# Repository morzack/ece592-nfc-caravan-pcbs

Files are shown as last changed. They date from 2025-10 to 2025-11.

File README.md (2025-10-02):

# ece592-nfc-caravan-pcbs

submodules vendor in reference boards for tt06 and caravel.

most up-to-date caravel evaluation PCB at `caravel_board/hardware/development/caravel-dev-v5-M.2` -- this contains details on FTDI module and flash memory for bringup of on-chip VexRiscv management CPU

## work breakdown

following a top-down design

1. make symbol for pinout (actual)
2. identify routing constaints for breakout
3. make block diagram of off-chip requirements for bringup
4. implement schematics for off-chip stuff
5. layout, etc

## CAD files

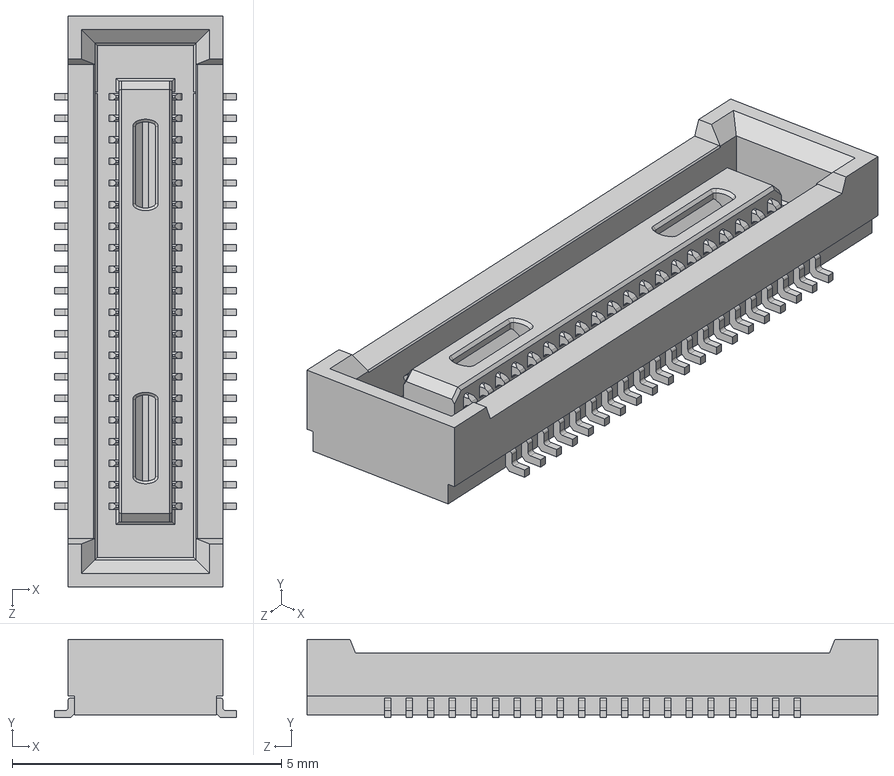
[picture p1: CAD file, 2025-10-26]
3D/DF40C-40DS-0.4V_51_.stp
3.38 x 1.45 x 10.6 mm

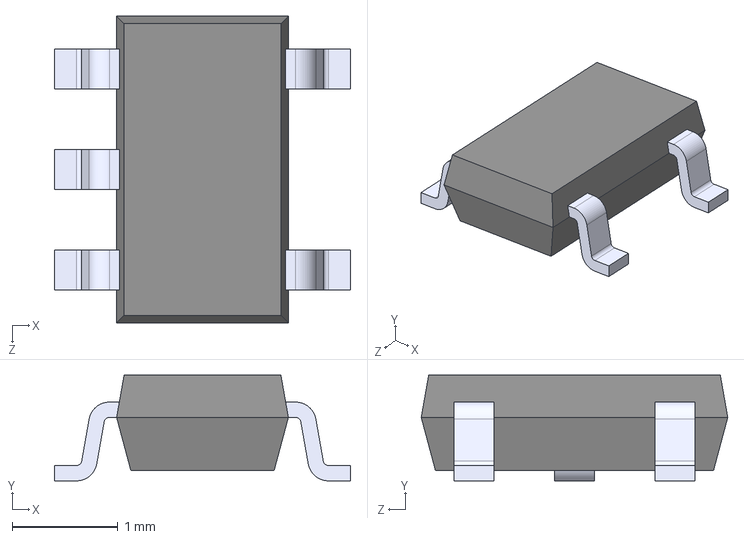
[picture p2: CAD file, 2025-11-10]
LT1761ES5_BYP_TRMPBF/LT1761ES5-BYPTRMPBF.step
2.80 x 1.00 x 2.90 mm

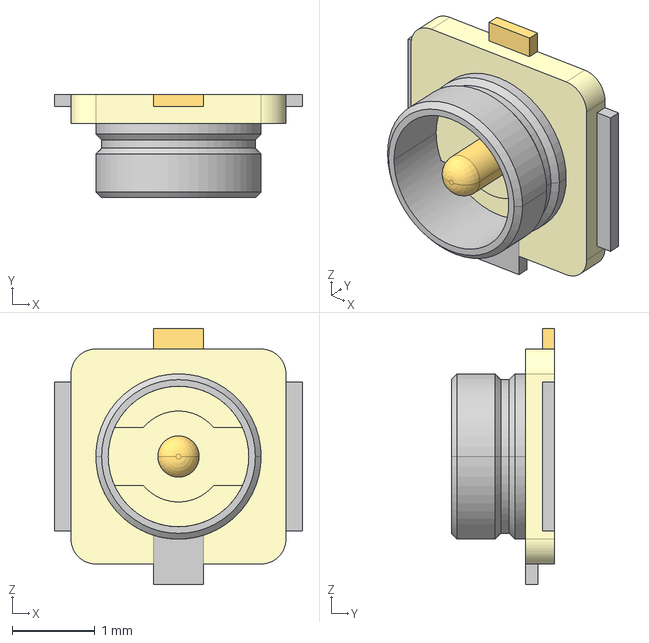
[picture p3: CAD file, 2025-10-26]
3D/U.FL-R-SMT-1_80_.stp
3.00 x 1.25 x 3.10 mm

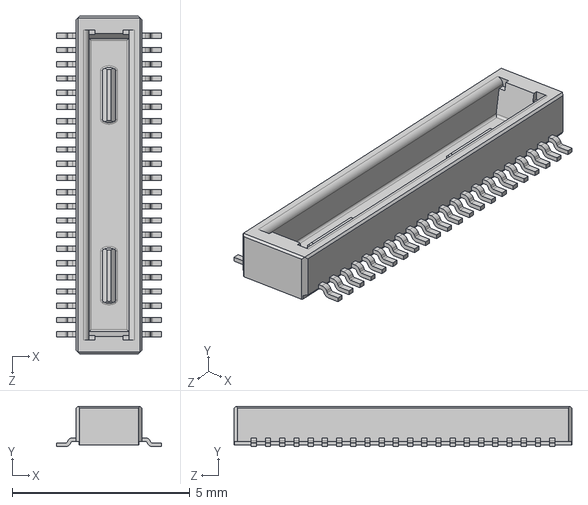
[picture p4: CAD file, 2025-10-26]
3D/DF40C-40DP-0.4V_51_.stp
2.97 x 1.14 x 9.52 mm

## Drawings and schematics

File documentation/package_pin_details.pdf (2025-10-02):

## Pad Assign Information

ESD | NO ESD | CLAMP | NO ESD

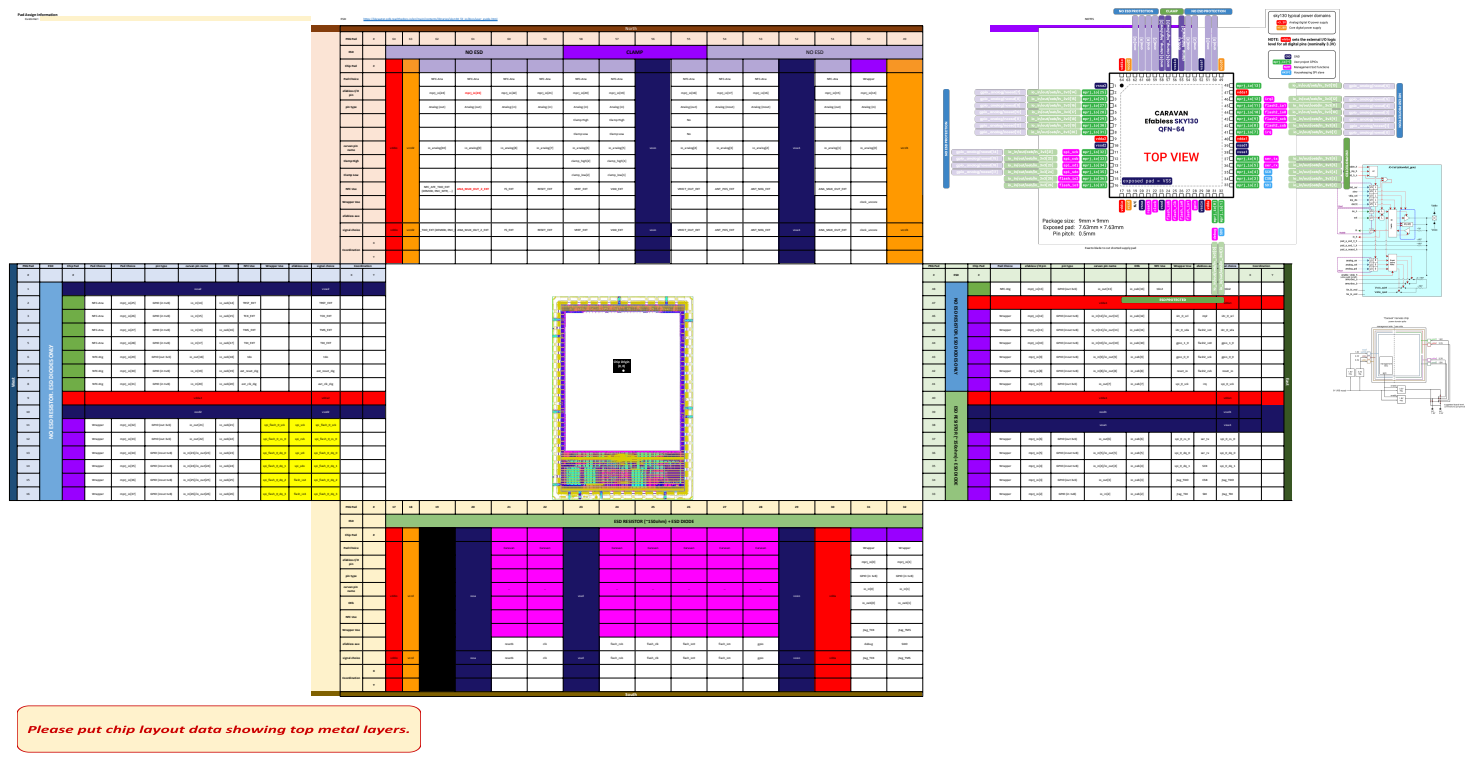
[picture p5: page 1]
Customer:; ESD; https://skywater-pdk.readthedocs.io/en/main/contents/libraries/sky130_fd_io/docs/user_guide.html; NOTES North; Claimed by Wrapper Team; PKG Pad; 21 GPIO left after Wrapper; Chip Pad; 11 bare pads on North; Pad Choice; vddio; vccd2; NFC-Ana; vssio; vssa1; Wrapper; vccd1; efabless I/O pin; mprj_io[24]; mprj_io[23]; mprj_io[22]; mprj_io[21]; mprj_io[20]; mprj_io[19]; mprj_io[18]; mprj_io[17]; mprj_io[16]; mprj_io[15]; mprj_io[14]; pin type; Analog (out); Analog (in)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

Clamps can be disabled by hooking their pins to GND

instead of VDD + GND

carvan pin name

Exacto blade to cut shorted supply pad

NO ESD RESISTOR. ESD DIODES ONLY

ESD RESISTOR (~150ohm) + ESD DIODE

Pad | Voltage (V) | Expected
Side Design | Pad # | Assigned Signal | Assigned Port | Connection (Analog GDS) | OEb | Connection | Clamp High | Connection | Clamp Low | Connection | Type | # of ports | Function | External | Core | Voltage Name Frequency Location (X) Location (Y) Notes:
Top | 0 | | | | | | | | | | | | | | | Need to add in more pins or extra continuous monitor ports if needed. One that is suggested is the output muxes to a digital pin so that we can monitor the AFE output while JTAG is in use by the digital team

# WEST

vssa2 | 1 | vssa2 | 0 | DC
NFC-Ana | 2 | TRST_EXT | io_in[14] | TRST_EXT | io_oeb[14] | GPIO (in 1v8) | 5 | JTAG | 3.3 | 1.8 | JTAG's reset
NFC-Ana | 3 | TCK_EXT | io_in[15] | TCK_EXT | io_oeb[15] | GPIO (in 1v8) | 5 | JTAG | 3.3 | 1.8 | 1MHz | JTAG's clock
NFC-Ana | 4 | TMS_EXT | io_in[16] | TMS_EXT | io_oeb[16] | GPIO (in 1v8) | 5 | JTAG | 3.3 | 1.8 | JTAG's Test Mode Select
NFC-Ana | 5 | TDI_EXT | io_in[17] | TDI_EXT | io_oeb[17] | GPIO (in 1v8) | 5 | JTAG | 3.3 | 1.8 | JTAG's TDI 1
NFC-Dig | 6 | tdo | io_out[18] | TDO_EXT | io_oeb[18] | GPIO (out 3v3) | 5 | JTAG | 3.3 | 1.8 | JTAG's TDO 1
NFC-Dig | 7 | ext_reset_dig | io_in[19] | io_oeb[19] | GPIO (in 1v8) | 1.8 | 1.8 | External reset signal (for digital)
NFC-Dig | 8 | ext_clk_dig | io_in[20] | io_oeb[20] | GPIO (in 1v8) | 1.8 | 1.8 | 4MHz | External carrier frequency clock (for digital)
vdda2 | 9 | vdda2 | 3.3
vssd2 | 10 | vssd2 | 0 Wrapper | 11 | spi_flash_0_sck | io_out[21] | io_oeb[21] | GPIO (out 3v3) | 6 | SPI FLASH | 3.3 | 1.8 | 10MHz | Wrapper SPI Flash Clock
Wrapper | 12 | spi_flash_0_cs_0 | io_out[22] | io_oeb[22] | GPIO (out 3v3) | 6 | SPI FLASH | 3.3 | 1.8 | Wrapper SPI Flash Chip Select
Wrapper | 13 | spi_flash_0_dq_0 | io_in[23]/io_out[23] | io_oeb[23] | GPIO (inout 1v8) | 6 | SPI FLASH | 3.3 | 1.8 | Wrapper SPI Flash DQ 0
Wrapper | 14 | spi_flash_0_dq_1 | io_in[24]/io_out[24] | io_oeb[24] | GPIO (inout 1v8) | 6 | SPI FLASH | 3.3 | 1.8 | Wrapper SPI Flash DQ 1
Wrapper | 15 | spi_flash_0_dq_2 | io_in[25]/io_out[25] | io_oeb[25] | GPIO (inout 1v8) | 6 | SPI FLASH | 3.3 | 1.8 | Wrapper SPI Flash DQ 2
Wrapper | 16 | spi_flash_0_dq_3 | io_in[26]/io_out[26] | io_oeb[26] | GPIO (inout 1v8) | 6 | SPI FLASH | 3.3 | 1.8 | Wrapper SPI Flash DQ 3

# SOUTH

vddio | 17 | vddio | 1.8 | 1.8
vccd | 18 | vccd | 1.8 | 1.8
Caravan | 19 | NC | NC
vssa | 20 | vssa | 0
Caravan | 21 | resetb | --
Caravan | 22 | clk | -- | ???
vssd | 23 | vssd | 0
Caravan | 24 | flash_csb | -- | ???
Caravan | 25 | flash_clk | -- | ???
Caravan | 26 | flash_io0 | -- | ???
Caravan | 27 | flash_io1 | -- | ???
Caravan | 28 | gpio | -- | ???
vssio | 29 | vssio | 0
vdda | 30 | vdda | 3.3 | 3.3 Wrapper | 31 | jtag_TCK | io_in[0] | io_oeb[0] | GPIO (in 1v8) | JTAG | 3.3 | 1.8 | 1MHz | Wrapper JTAG clock
Wrapper | 32 | jtag_TMS | io_in[1] | io_oeb[1] | GPIO (in 1v8) | JTAG | 3.3 | 1.8 | Wrapper JTAG mode select
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

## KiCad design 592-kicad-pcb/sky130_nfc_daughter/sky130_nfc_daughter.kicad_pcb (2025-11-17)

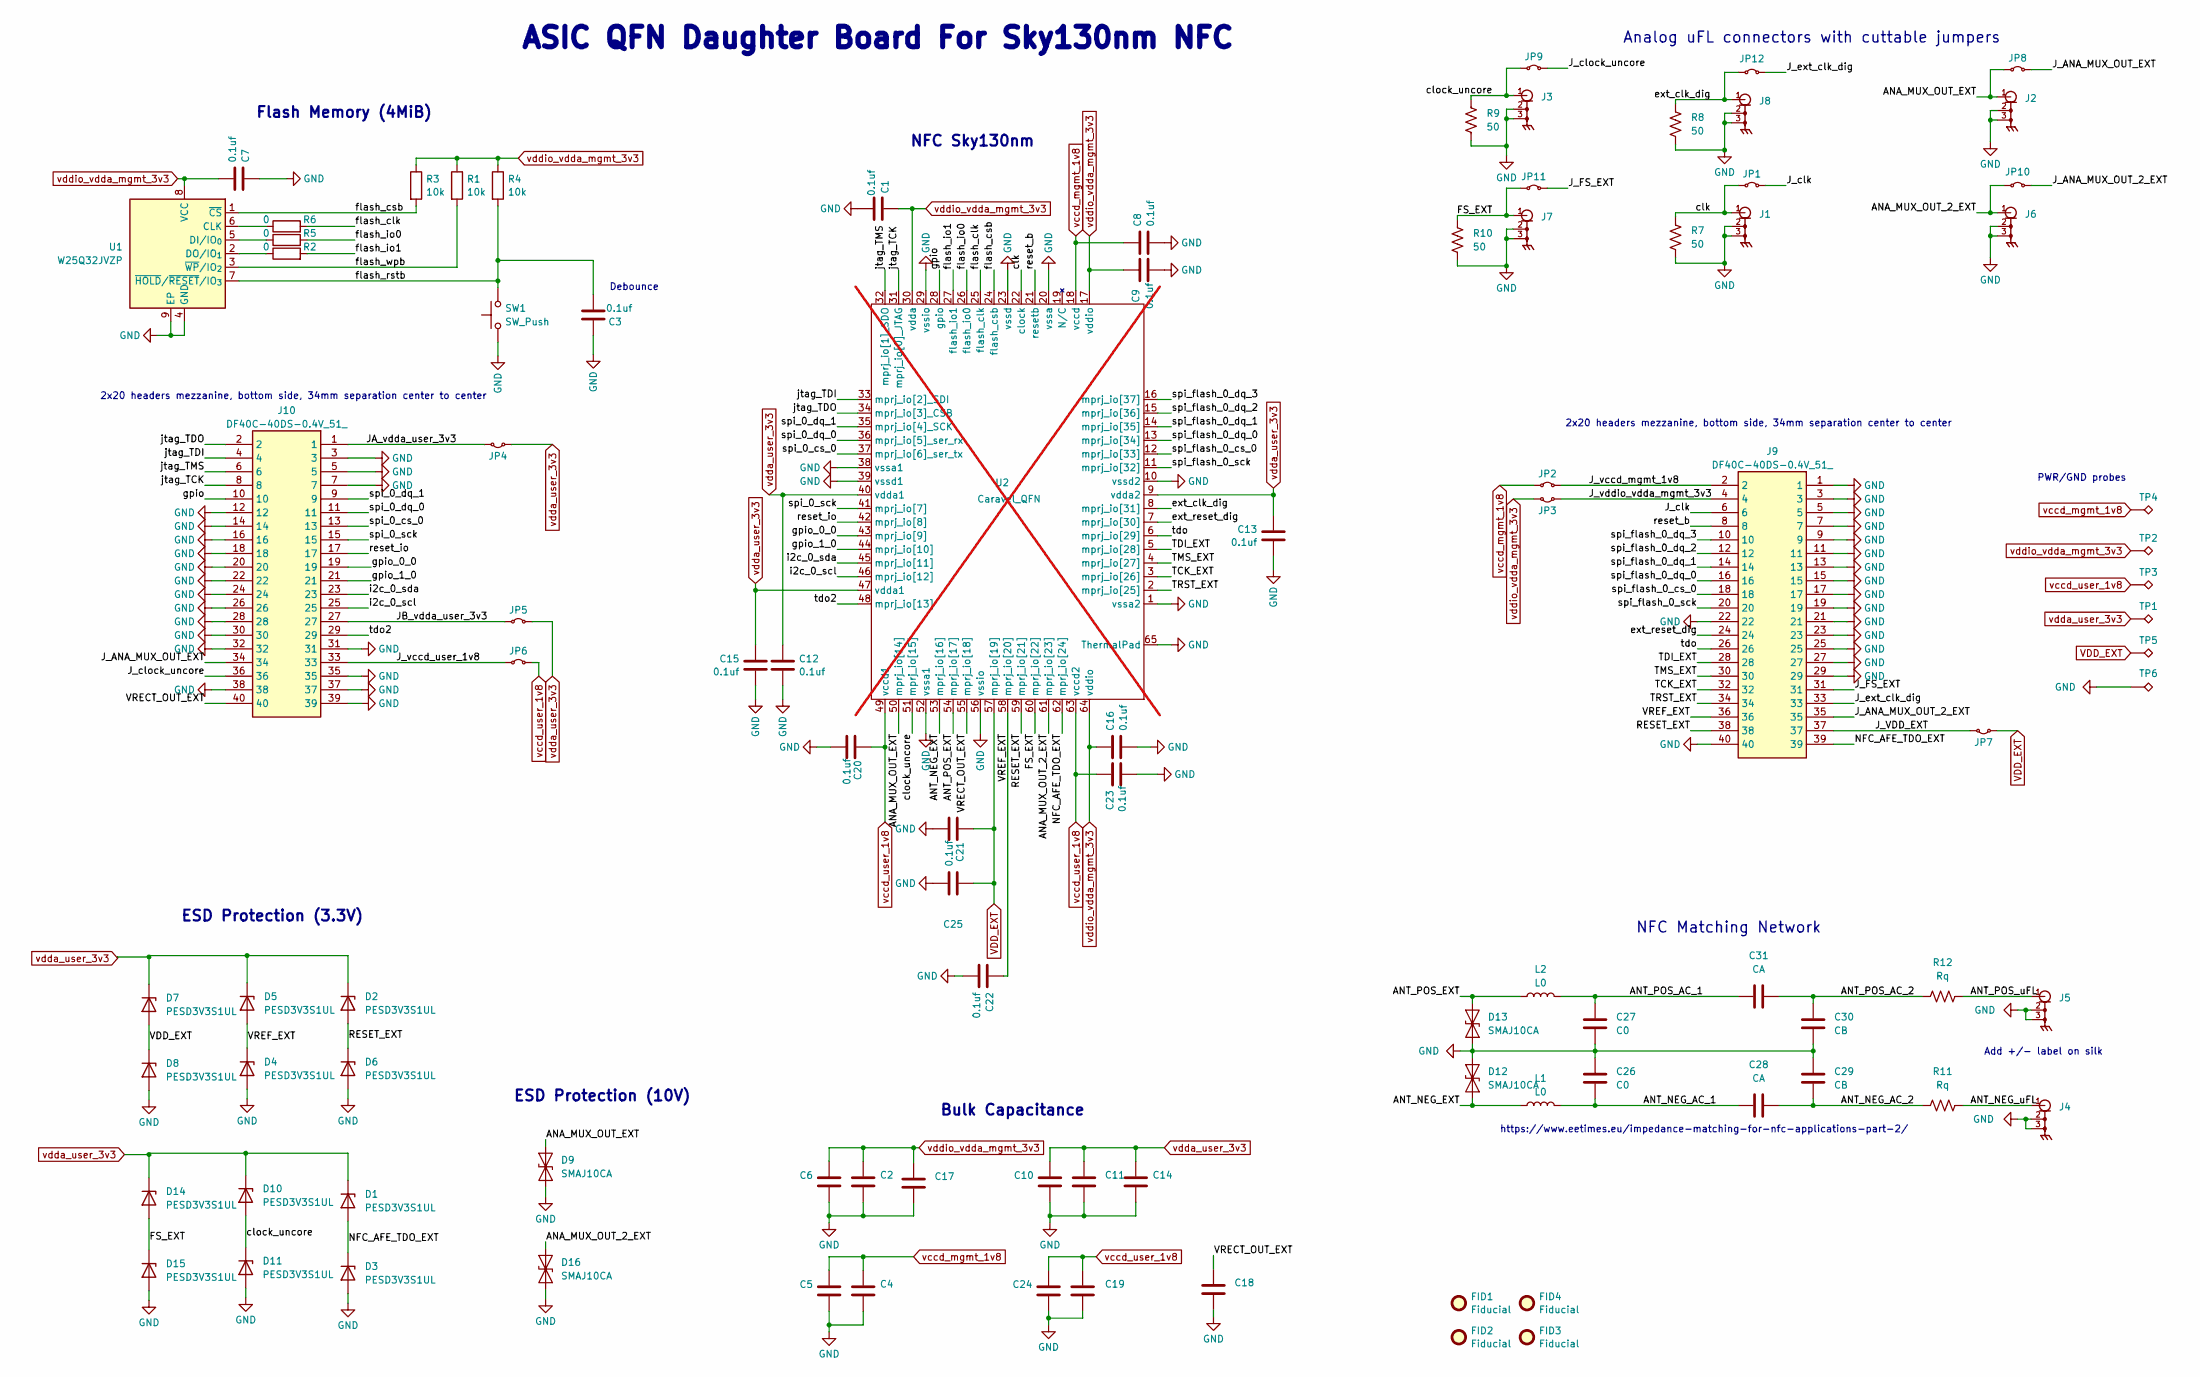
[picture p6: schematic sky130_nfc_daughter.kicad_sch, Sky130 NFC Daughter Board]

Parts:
C1, C3, C7, C8, C9, C12, C13, C15, C16, C20, C21, C22, C23: 0.1uf; C_0402_1005Metric
C2, C4, C5, C6, C10, C11, C14, C17, C18, C19, C24, C25: C_1u_0603_50V; C_0603_1608Metric
C26, C27: C0; C_0603_1608Metric_Pad1.08x0.95mm_HandSolder
C28, C31: CA; C_0603_1608Metric_Pad1.08x0.95mm_HandSolder
C29, C30: CB; C_0603_1608Metric_Pad1.08x0.95mm_HandSolder
D1, D2, D3, D4, D5, D6, D7, D8, D10, D11, D14, D15: PESD3V3S1UL; D_SOD-882
D9, D12, D13, D16: SMAJ10CA; D_SMA
FID1, FID2, FID3, FID4: Fiducial; Fiducial_1mm_Mask2mm
J1, J2, J3, J4, J5, J6, J7, J8: U.FL-R-SMT-1_80_; UFLRSMT180
J9, J10: DF40C-40DS-0.4V_51_; DF40C40DS04V51
JP1, JP2, JP3, JP4, JP5, JP6, JP7, JP8, JP9, JP10, JP11, JP12: Jumper_2_Small_Bridged; SolderJumper-2_P1.3mm_Bridged_RoundedPad1.0x1.5mm
L1, L2: L0; L_0603_1608Metric_Pad1.05x0.95mm_HandSolder
R1, R3, R4: 10k; R_0402_1005Metric
R2, R5, R6: 0; R_0402_1005Metric
R7, R8, R9, R10: 50; R_0402_1005Metric
R11, R12: Rq; R_0603_1608Metric_Pad0.98x0.95mm_HandSolder
SW1: SW_Push; SW_Push_1P1T_XKB_TS-1187A
TP1, TP2, TP3, TP4, TP5, TP6: TestPoint_Alt; TestPoint_Keystone_5019_Minature; MPN 5019; DigikeyPN 36-5019CT-ND
U1: W25Q32JVZP; WSON-8-1EP_6x5mm_P1.27mm_EP3.4x4.3mm
U2: Caravel_QFN; QFN-64-1EP_9x9mm_P0.5mm_EP7.65x7.65mm_SMALL_EPAD; not fitted

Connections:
/ANA_MUX_OUT_2_EXT: D16.2 (A2), J6.1, JP10.1 (A), U2.61 (mprj_io[23])
/ANA_MUX_OUT_EXT: D9.2 (A2), J2.1, JP8.1 (A), U2.50 (mprj_io[14])
/ANT_NEG_AC_1: C26.2, C28.1, L1.2
/ANT_NEG_AC_2: C28.2, C29.2, R11.1
/ANT_NEG_EXT: D12.2 (A2), L1.1, U2.53 (mprj_io[16])
/ANT_NEG_uFL: J4.1, R11.2
/ANT_POS_AC_1: C27.1, C31.1, L2.2
/ANT_POS_AC_2: C30.1, C31.2, R12.1
/ANT_POS_EXT: D13.2 (A2), L2.1, U2.54 (mprj_io[17])
/ANT_POS_uFL: J5.1, R12.2
/FS_EXT: D14.2 (A), D15.1 (K), J7.1, JP11.1 (A), R10.2, U2.60 (mprj_io[22])
/JA_vdda_user_3v3: J10.1, JP4.1 (A)
/JB_vdda_user_3v3: J10.27, JP5.2 (B)
/J_ANA_MUX_OUT_2_EXT: J9.35, JP10.2 (B)
/J_ANA_MUX_OUT_EXT: J10.34, JP8.2 (B)
/J_FS_EXT: J9.31, JP11.2 (B)
/J_VDD_EXT: J9.37, JP7.1 (A)
/J_clk: J9.6, JP1.2 (B)
/J_clock_uncore: J10.36, JP9.2 (B)
/J_ext_clk_dig: J9.33, JP12.2 (B)
/J_vccd_mgmt_1v8: J9.2, JP2.1 (A)
/J_vccd_user_1v8: J10.33, JP6.2 (B)
/J_vddio_vdda_mgmt_3v3: J9.4, JP3.1 (A)
/NFC_AFE_TDO_EXT: D1.2 (A), D3.1 (K), J9.39, U2.62 (mprj_io[24])
/RESET_EXT: D2.2 (A), D6.1 (K), J9.38, U2.59 (mprj_io[21])
/TCK_EXT: J9.32, U2.3 (mprj_io[26])
/TDI_EXT: J9.28, U2.5 (mprj_io[28])
/TMS_EXT: J9.30, U2.4 (mprj_io[27])
/TRST_EXT: J9.34, U2.2 (mprj_io[25])
/VRECT_OUT_EXT: C18.1, J10.40, U2.55 (mprj_io[18])
/VREF_EXT: C22.1, D4.1 (K), D5.2 (A), J9.36, U2.58 (mprj_io[20])
/clk: J1.1, JP1.1 (A), R7.2, U2.22 (clock)
/clock_uncore: D10.2 (A), D11.1 (K), J3.1, JP9.1 (A), R9.2, U2.51 (mprj_io[15])
/ext_clk_dig: J8.1, JP12.1 (A), R8.2, U2.8 (mprj_io[31])
/ext_reset_dig: J9.24, U2.7 (mprj_io[30])
/flash_clk: R6.2, U2.25 (flash_clk)
/flash_csb: R3.2, U1.1 (~CS), U2.24 (flash_csb)
/flash_io0: R5.2, U2.26 (flash_io0)
/flash_io1: R2.2, U2.27 (flash_io1)
/flash_rstb: C3.1, R4.2, SW1.2, U1.7 (~HOLD/~RESET/IO_{3})
/flash_wpb: R1.2, U1.3 (~WP/IO_{2})
/gpio: J10.10, U2.28 (gpio)
/gpio_0_0: J10.19, U2.43 (mprj_io[9])
/gpio_1_0: J10.21, U2.44 (mprj_io[10])
/i2c_0_scl: J10.25, U2.46 (mprj_io[12])
/i2c_0_sda: J10.23, U2.45 (mprj_io[11])
/jtag_TCK: J10.8, U2.31 (mprj_io[0]_JTAG)
/jtag_TDI: J10.4, U2.33 (mprj_io[2]_SDI)
/jtag_TDO: J10.2, U2.34 (mprj_io[3]_CSB)
/jtag_TMS: J10.6, U2.32 (mprj_io[1]_SDO)
/reset_b: J9.8, U2.21 (resetb)
/reset_io: J10.17, U2.42 (mprj_io[8])
/spi_0_cs_0: J10.13, U2.37 (mprj_io[6]_ser_tx)
/spi_0_dq_0: J10.11, U2.36 (mprj_io[5]_ser_rx)
/spi_0_dq_1: J10.9, U2.35 (mprj_io[4]_SCK)
/spi_0_sck: J10.15, U2.41 (mprj_io[7])
/spi_flash_0_cs_0: J9.18, U2.12 (mprj_io[33])
/spi_flash_0_dq_0: J9.16, U2.13 (mprj_io[34])
/spi_flash_0_dq_1: J9.14, U2.14 (mprj_io[35])
/spi_flash_0_dq_2: J9.12, U2.15 (mprj_io[36])
/spi_flash_0_dq_3: J9.10, U2.16 (mprj_io[37])
/spi_flash_0_sck: J9.20, U2.11 (mprj_io[32])
/tdo: J9.26, U2.6 (mprj_io[29])
/tdo2: J10.29, U2.48 (mprj_io[13])
GND: C1.1, C2.2, C3.2, C4.2, C5.2, C6.2, C7.1, C8.1, C9.1, C10.2, C11.2, C12.2, C13.1, C14.2, C15.2, C16.1, C17.2, C18.2, C19.2, C20.2, C21.2, C22.2, C23.1, C24.2, C25.1, C26.1, C27.2, C29.1, C30.2, D3.2 (A), D4.2 (A), D6.2 (A), D8.2 (A), D9.1 (A1), D11.2 (A), D12.1 (A1), D13.1 (A1), D15.2 (A), D16.1 (A1), J1.2, J1.3, J2.2, J2.3, J3.2, J3.3, J4.2, J4.3, J5.2, J5.3, J6.2, J6.3, J7.2, J7.3, J8.2, J8.3, J9.1, J9.3, J9.5, J9.7, J9.9, J9.11, J9.13, J9.15, J9.17, J9.19, J9.21, J9.22, J9.23, J9.25, J9.27, J9.29, J9.40, J10.3, J10.5, J10.7, J10.12, J10.14, J10.16, J10.18, J10.20, J10.22, J10.24, J10.26, J10.28, J10.30, J10.31, J10.32, J10.35, J10.37, J10.38, J10.39, R7.1, R8.1, R9.1, R10.1, SW1.1, TP6.1, U1.4 (GND), U1.9 (EP), U2.1 (vssa2), U2.10 (vssd2), U2.20 (vssa), U2.23 (vssd), U2.29 (vssio), U2.38 (vssa1), U2.39 (vssd1), U2.52 (vssa1), U2.56 (vssio), U2.65 (ThermalPad); also elsewhere on the board
unnamed: R6.1, U1.6 (CLK)
unnamed: R5.1, U1.5 (DI/IO_{0})
unnamed: R2.1, U1.2 (DO/IO_{1})
VDD_EXT: C21.1, C25.2, D7.2 (A), D8.1 (K), JP7.2 (B), TP5.1, U2.57 (mprj_io[19])
vccd_mgmt_1v8: C4.1, C5.1, C8.2, JP2.2 (B), TP4.1, U2.18 (vccd)
vccd_user_1v8: C19.1, C20.1, C23.2, C24.1, JP6.1 (A), TP3.1, U2.49 (vccd1), U2.63 (vccd2)
vdda_user_3v3: C10.1, C11.1, C12.1, C13.2, C14.1, C15.1, D1.1 (K), D2.1 (K), D5.1 (K), D7.1 (K), D10.1 (K), D14.1 (K), JP4.2 (B), JP5.1 (A), TP1.1, U2.9 (vdda2), U2.40 (vdda1), U2.47 (vdda1)
vddio_vdda_mgmt_3v3: C1.2, C2.1, C6.1, C7.2, C9.2, C16.2, C17.1, JP3.2 (B), R1.1, R3.1, R4.1, TP2.1, U1.8 (VCC), U2.17 (vddio), U2.30 (vdda), U2.64 (vddio)

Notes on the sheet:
ESD Protection (10V)
2x20 headers mezzanine, bottom side, 34mm separation center to center
https://www.eetimes.eu/impedance-matching-for-nfc-applications-part-2/
ASIC QFN Daughter Board For Sky130nm NFC
NFC Sky130nm
PWR/GND probes
Flash Memory (4MiB)
Debounce
Bulk Capacitance
NFC Matching Network
ESD Protection (3.3V)
Analog uFL connectors with cuttable jumpers
Add +/- label on silk

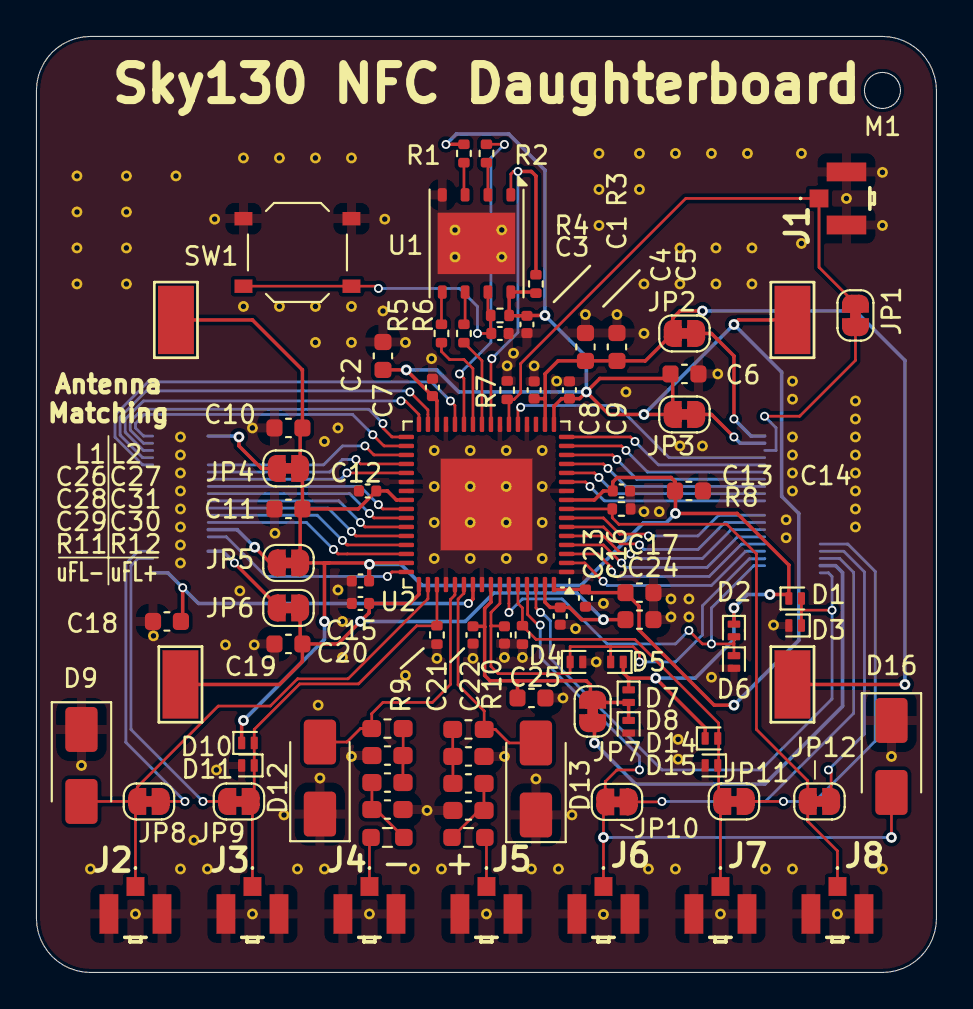
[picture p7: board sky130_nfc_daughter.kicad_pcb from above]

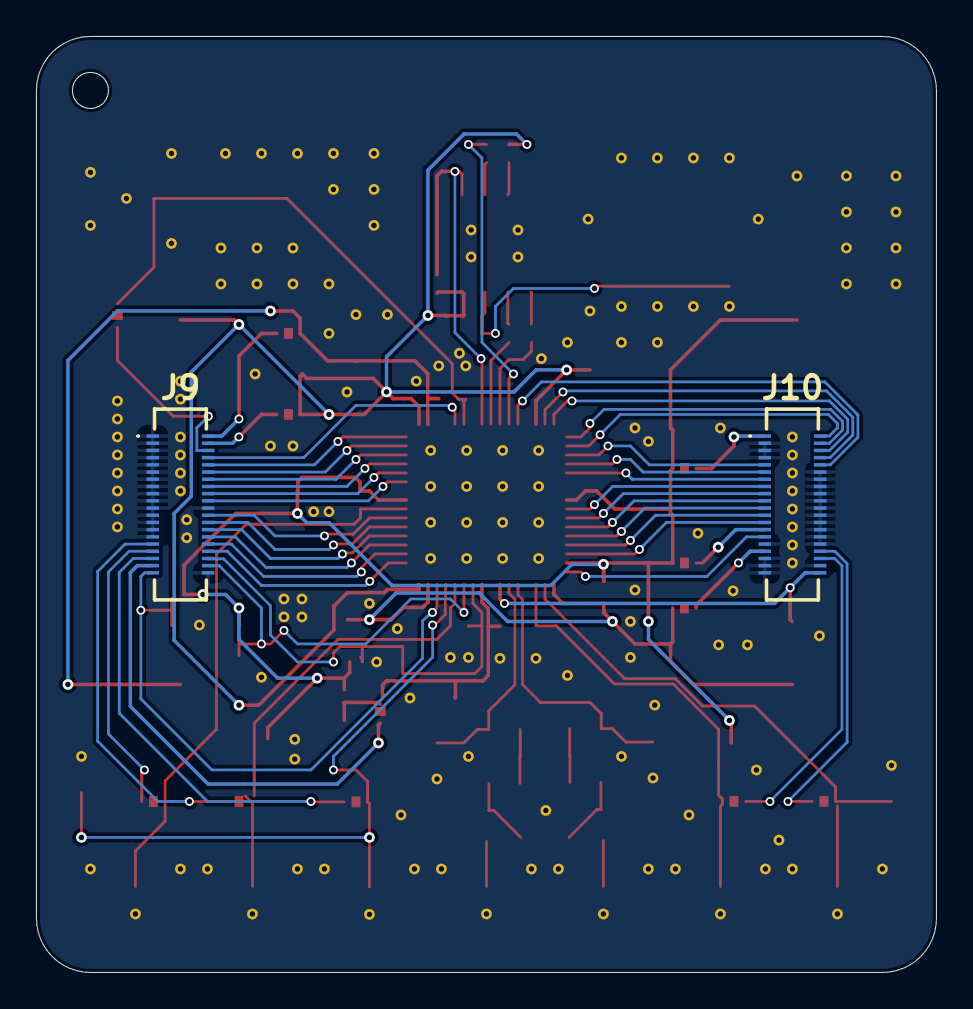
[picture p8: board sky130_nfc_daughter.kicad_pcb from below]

Board: 4 copper layers, 50.0 x 52.0 mm, 96 parts (2 on the bottom side), 73 nets.

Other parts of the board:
M1: MountingHole_2mm
STITCHM1, STITCHM2, STITCHM3, STITCHM4, STITCHM5: STITCHING_VIA_0p3mm

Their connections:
GND: STITCHM1.1, STITCHM2.1, STITCHM3.1, STITCHM4.1, STITCHM5.1; also elsewhere on the board

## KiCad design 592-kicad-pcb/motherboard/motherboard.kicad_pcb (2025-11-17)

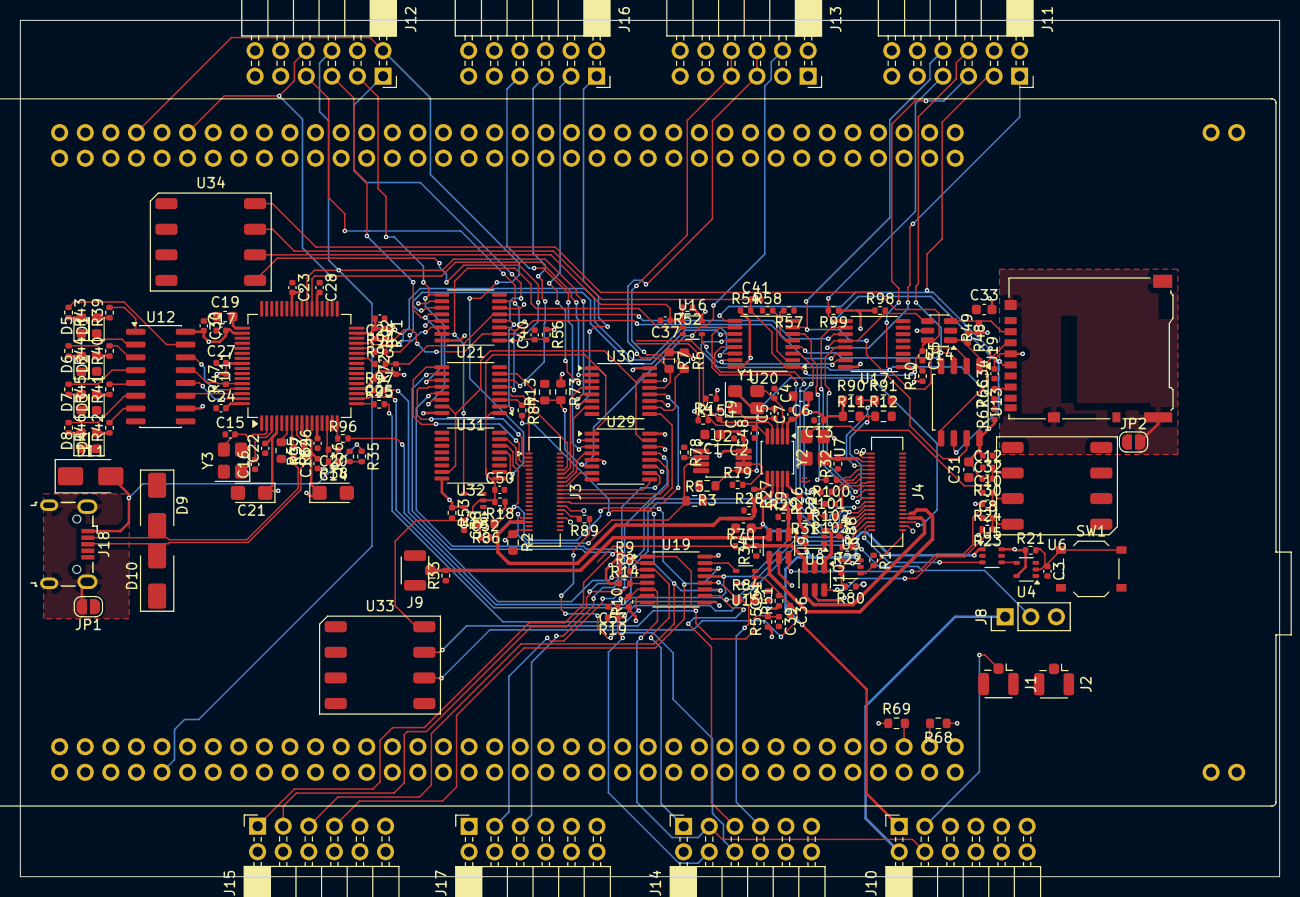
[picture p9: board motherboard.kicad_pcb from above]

Board: 4 copper layers, 125.0 x 85.0 mm, 194 parts (0 on the bottom side), 176 nets.

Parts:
C1, C6, C11, C31, C33: 1u; C_0603_1608Metric
C2, C3, C7, C8, C9, C10, C12, C17, C18, C22, C23, C24, C25, C26, C27, C28, C29, C30, C32, C34, C35, C36, C37, C38, C39, C40, C41, C50: 100n; C_0402_1005Metric
C4, C5: 16p; C_0402_1005Metric
C13, C20, C53: 10n; C_0402_1005Metric
C14, C21: 4.7u; CP_EIA-3216-18_Kemet-A
C15, C16: 10p; C_0402_1005Metric
C19: 3.3u; C_0603_1608Metric
C48, C49: 0; C_0402_1005Metric
C51, C52: 100p; C_0402_1005Metric
D1, D2, D3, D4: d_white; D_0603_1608Metric
D5, D6, D7, D8: d_red; D_0603_1608Metric
D9, D10, D11: SMAJ10CA; D_SMA
J1, J2, J9: U.FL; U.FL_Hirose_U.FL-R-SMT-1_Vertical
J3, J4: DF40C-40DP-0.4V(51); Hirose_DF40C(2.0)-40DS-0.4V_2x20_P0.4mm
J8: 2.54mm jumper; PinHeader_1x03_P2.54mm_Vertical
J10, J11, J12, J13, J14, J15, J16, J17: Conn_02x06_Odd_Even; PinSocket_2x06_P2.54mm_Horizontal
J18: USB_B_Micro; USB_Micro-B_Wuerth_629105150521
J19: Micro_SD_Card; microSD_HC_Hirose_DM3AT-SF-PEJM5
JP1, JP2: solderjump; SolderJumper-2_P1.3mm_Open_RoundedPad1.0x1.5mm
R1: 1M; R_0402_1005Metric
R2, R3, R5: 10M; R_0603_1608Metric
R4, R15: 5k; R_0402_1005Metric
R6, R7: 2k; R_0603_1608Metric
R8, R9, R10, R14, R18, R19, R21, R23, R24, R28, R29, R30, R31, R32, R33, R34, R36, R47, R50, R51, R52, R53, R54, R55, R56, R57, R58, R67, R71, R72, R92, R98, R99: 10k; R_0402_1005Metric
R11, R12, R13, R73, R90, R91: 10k; R_0603_1608Metric
R22, R48, R49: 100k; R_0402_1005Metric
R25, R26, R27: 10; R_0402_1005Metric
R35: 4.7k; R_0402_1005Metric
R37: 12k <1%; R_0603_1608Metric
R38: 1k; R_0402_1005Metric
R39, R40, R41, R42: 150; R_0402_1005Metric
R43, R44, R45, R46: 330; R_0402_1005Metric
R64, R65, R70, R87, R88, R89, R100, R101, R102, R103: 0; R_0402_1005Metric
R66: 27; R_0402_1005Metric
R68, R69: 5k; R_0603_1608Metric
R78, R79, R80: 100; R_0402_1005Metric
R84, R86: 75; R_0603_1608Metric
R93, R94, R95, R96, R97: 22; R_0402_1005Metric
SW1: C318884; SW_Push_1P1T_XKB_TS-1187A
U1: NUCLEO144-H743ZI; ST_Morpho_Connector_144_STLink
U2: OPA2328DGKR; VSSOP-8_3x3mm_P0.65mm
U3, U5, U8: 74LVC1T45GW; SOT-363_SC-70-6
U4, U15, U18: SN74LVC1G14DBV; SOT-353_SC-70-5
U6, U33, U34: SMXS-04K; SMXS-04K-TP
U7: SX3M10.000B10F20TNN; Crystal_SMD_3225-4Pin_3.2x2.5mm
U9, U10, U14: SN74LVC1G3157DBVR; SOT-23-6
U11: FT4232H; LQFP-64_10x10mm_P0.5mm
U12: 74HC595; SOIC-16_3.9x9.9mm_P1.27mm
U13: W25Q32JVSS; SOIC-8_5.3x5.3mm_P1.27mm
U16: SN74LVC1G00DCK; SOT-353_SC-70-5
U17, U19, U20, U21, U29, U30, U31, U32: 74CBTLV3257PW,118; TSSOP-16_4.4x5mm_P0.65mm
Y1: NX3225GA-25.000M-STD-CRG-2; Crystal_SMD_3225-4Pin_3.2x2.5mm
Y2: Si5351A; MSOP-10_3x3mm_P0.5mm
Y3: X322512MSB4SI; Crystal_SMD_3225-4Pin_3.2x2.5mm

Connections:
+1V8: C9.1, C11.1, J10.1, U3.6 (VCCB), U5.1 (VCCA), U8.6 (VCCB), Y2.7 (VDDO)
+3V3: C1.1, C2.1, C6.1, C7.1, C13.1, C14.1, C17.2, C18.2, C21.1, C22.2, C23.2, C25.2, C27.2, C29.2, C30.2, C31.2, C32.2, C33.2, C34.2, J10.11, J10.12, J11.11, J11.12, J12.11, J12.12, J13.11, J13.12, J14.11, J14.12, J15.11, J15.12, J16.11, J16.12, J17.11, J17.12, J19.4 (VDD), R4.1, R6.1, R7.1, R8.1, R9.1, R10.1, R11.1, R14.1, R15.1, R18.1, R21.1, R23.2, R24.2, R30.2, R47.2, R48.1, R49.1, R50.1, R51.1, R52.1, R53.1, R54.1, R55.1, R56.1, R67.1, R68.1, R69.1, R71.1, R72.1, R73.1, R90.1, R92.1, R98.1, R99.1, U2.8 (Vdd), U3.1 (VCCA), U4.5 (VCC), U5.6 (VCCB), U7.4 (VDD), U8.1 (VCCA), U9.5 (VCC), U10.5 (VCC), U11.4 (VPHY), U11.9 (VPLL), U11.20 (VCCIO), U11.31 (VCCIO), U11.42 (VCCIO), U11.50 (VREGIN), U11.56 (VCCIO), U12.10 (~SRCLR), U12.16 (VCC), U13.8 (VCC), U14.5 (VCC), U15.5 (VCC), U16.5 (VCC), U17.16 (VCC), U18.5 (VCC), U19.16 (VCC), U20.16 (VCC), U21.16 (VCC), U29.16 (VCC), U30.16 (VCC), U31.16 (VCC), U32.16 (VCC), Y2.1 (VDD)
/PA0_UART4_RX: U1.28 (PA0), U11.48 (DDBUS0)
/PA1_UART4_TX: U1.30 (ETH_REF_CLK/PA1), U11.52 (DDBUS1)
/PA4_DAC_OUT1: J8.3, U1.32 (PA4)
/PB8_I2C4_SCL: C49.2, R15.2, R68.2, U1.75 (PB8), Y2.4 (SCL)
/PB9_I2C4_SDA: C48.2, R4.2, R69.2, U1.77 (PB9), Y2.5 (SDA)
/PB14_TIM12_CH1: R70.1, U1.100 (LD3/PB14)
/PD7: U1.45 (PD7), U30.14
/PE0_UART8_RX: J12.6, U1.136 (PE0), U11.39 (CDBUS1), U30.5
/PE1_UART8_TX: J12.8, U1.61 (PE1), U11.38 (CDBUS0), U30.2
/PF6_SPI5_CS: U1.9 (PF6), U21.3
/PF7_SPI5_SCK: U1.11 (PF7), U21.6
/PF8_SPI5_MISO: U1.54 (PF8), U21.13
/PF9_SPI5_MOSI: U1.56 (PF9), U21.10
/PG0: U1.59 (PG0), U29.14
/PG1: U1.58 (PG1), U30.11
/PG9: U1.63 (PG9), U29.11
/PG10: U1.66 (PG10), U29.2
/PG12: J12.2, U1.65 (PG12), U32.5
/PG15: U1.64 (PG15), U29.5
/motherboard_top/ADC_chip_ana_mux_out_1: J1.1 (In), J10.3, R78.1
/motherboard_top/ADC_chip_ana_mux_out_2: J2.1 (In), J10.5, R79.1
/motherboard_top/GPIO_JTAG_FTDI_source_select: C39.1, R55.2, U19.1 (S), U33.7 (2o)
/motherboard_top/GPIO_MGMT_enable: C38.1, C50.1, R18.2, R53.2, U18.2, U29.1 (S), U30.1 (S), U31.1 (S), U32.1 (S), U33.8 (1o)
/motherboard_top/GPIO_SPI_MGMT_source_sel: C40.1, R56.2, U21.1 (S), U34.5 (4o)
/motherboard_top/GPIO_chip_nfc_afe_tdo_ext: J10.7, R80.1
/motherboard_top/GPIO_chip_nfc_ext_reset_dig: J4.23, J10.6, R11.2, R12.1
/motherboard_top/GPIO_chip_nfc_jtag_tdo: J14.5, R88.2, U19.10
/motherboard_top/GPIO_chip_nfc_jtag_tdo2: J14.6, R89.1
/motherboard_top/GPIO_chip_rck_reset_io: J13.4, R13.1, R73.2, U29.6
/motherboard_top/GPIO_ftdi_jtag_src_en: C36.1, R51.2, U15.2, U33.6 (3o)
/motherboard_top/GPIO_rck_mem_sel_sdB: C35.1, R50.2, U14.6 (S), U34.8 (1o)
/motherboard_top/GPIO_rck_mem_source_en: C37.1, R52.2, U16.1, U34.6 (3o)
/motherboard_top/GPIO_rck_mem_source_sel_ftdiB: C41.1, R54.2, U17.1 (S), U20.1 (S), U34.7 (2o)
/motherboard_top/ana_buffers/a1: R78.2, U2.1 (Vout1), U2.2 (Vin1m)
/motherboard_top/ana_buffers/a2: R79.2, U2.6 (Vin2m), U2.7 (Vout2)
/motherboard_top/anamisc_vref_ext_in: J8.1, J10.2
/motherboard_top/chip_connection/mprj_io_0: J3.7, U32.7
/motherboard_top/chip_connection/mprj_io_1: J3.5, U31.9
/motherboard_top/chip_connection/mprj_io_2: J3.3, U31.12
/motherboard_top/chip_connection/mprj_io_3: J3.1, U31.4
/motherboard_top/chip_connection/mprj_io_4: J3.10, U31.7
/motherboard_top/chip_connection/mprj_io_5: J3.12, U30.4
/motherboard_top/chip_connection/mprj_io_6: J3.14, U30.7
/motherboard_top/chip_connection/mprj_io_7: J3.16, U29.4
/motherboard_top/chip_connection/mprj_io_8: J3.18, U29.7
/motherboard_top/chip_connection/mprj_io_9: J3.20, U29.9
/motherboard_top/chip_connection/mprj_io_10: J3.22, U29.12
/motherboard_top/chip_connection/mprj_io_11: J3.24, U30.9
/motherboard_top/chip_connection/mprj_io_12: J3.26, U30.12
/motherboard_top/chip_connection/resetb: J4.7, R90.2, R91.1
/motherboard_top/chip_connection/user_3v3: J3.2, J3.28
/motherboard_top/chip_nfc_ana_mux_out: J3.33, R5.1, U2.3 (Vin1p)
/motherboard_top/chip_nfc_ana_mux_out_2: J4.36, R3.1, U2.5 (Vin2p)
/motherboard_top/chip_nfc_ext_clk_dig: J4.34, U10.4 (A)
/motherboard_top/chip_nfc_fs: J4.32, U9.4 (A)
/motherboard_top/chip_nfc_jtag_tck: J4.31, J14.7, R84.1, U19.13
/motherboard_top/chip_nfc_jtag_tdi: J4.27, J10.4, J14.3, R10.2, U19.6
/motherboard_top/chip_nfc_jtag_tms: J4.29, J14.1, R8.2, U19.3
/motherboard_top/chip_nfc_jtag_trst: C53.1, J4.33, J14.4, R19.1
/motherboard_top/chip_nfc_nfc_afe_tdo: J4.40, R1.2, U3.4 (B)
/motherboard_top/chip_nfc_reset: J4.37, U5.3 (A)
/motherboard_top/chip_nfc_vrect_out: J3.39, J10.8, R2.1
/motherboard_top/chip_nfc_vref: J4.35, J8.2, R22.1
/motherboard_top/chip_rck_clock_uncore: J3.35, R27.2, R28.2
/motherboard_top/chip_rck_gpio_0_0: J17.5, U29.10
/motherboard_top/chip_rck_gpio_1_0: J17.3, U29.13
/motherboard_top/chip_rck_i2c_scl: J13.5, J13.6, R7.2, U30.13
/motherboard_top/chip_rck_i2c_sda: J13.7, J13.8, R6.2, U30.10
/motherboard_top/chip_rck_jtag_tck: J15.7, R86.1, U19.14, U32.6
/motherboard_top/chip_rck_jtag_tdi: J15.3, R14.2, U19.5, U31.13
/motherboard_top/chip_rck_jtag_tdo: J15.5, R87.2, U19.11
/motherboard_top/chip_rck_jtag_tms: J15.1, R9.2, U19.2, U31.10
/motherboard_top/chip_rck_spi_0_cs_0: J16.1, U30.6
/motherboard_top/chip_rck_spi_0_dq_0_mosi: J16.3, U30.3
/motherboard_top/chip_rck_spi_0_dq_1_miso: J16.5, U31.6
/motherboard_top/chip_rck_spi_0_sck: J16.7, U29.3
/motherboard_top/chip_spi_flash_0_cs_0: J4.17, U17.13
/motherboard_top/chip_spi_flash_0_dq_0: R103.2, U20.10
/motherboard_top/chip_spi_flash_0_dq_1: R102.2, U20.13
/motherboard_top/chip_spi_flash_0_dq_2: R101.2, U20.3
/motherboard_top/chip_spi_flash_0_dq_3: R100.2, U20.6
/motherboard_top/chip_spi_flash_0_sck: J4.19, U17.10
/motherboard_top/chip_support_misc/GPIO_RESET_EXT: C3.1, R21.2, SW1.1 (A), U4.2
/motherboard_top/clock_sources/CARAVEL_CLK_EN: C12.2, R30.1, U6.6 (3o), U7.1 (OE)
/motherboard_top/clock_sources/EXT_CLK_DIG_SEL: C8.2, R23.1, U6.8 (1o), U10.6 (S)
/motherboard_top/clock_sources/FS_EXT_SEL: C10.2, R24.1, U6.7 (2o), U9.6 (S)
/motherboard_top/clock_sources/ext_clk_dig_gen: R25.2, R31.2, U8.4 (B)
/motherboard_top/clock_sources/fs_ext_aux: J9.1 (In), R33.2, U9.3 (B1)
/motherboard_top/clock_sources/fs_ext_gen: R26.2, R29.2, U9.1 (B2)
/motherboard_top/ftdi1_jtag_tck: R96.2, U19.12
/motherboard_top/ftdi1_jtag_tdi: R95.2, U19.7
/motherboard_top/ftdi1_jtag_tdo: U11.18 (ADBUS2), U19.9
/motherboard_top/ftdi1_jtag_tms: R97.2, U19.4
/motherboard_top/ftdi/FTDI_RESETb: C20.2, R38.2, U11.14 (~RESET)
/motherboard_top/ftdi/USB_DM: D9.2 (A2), J18.2 (D-), R64.2
/motherboard_top/ftdi/USB_DP: D10.2 (A2), J18.3 (D+), R65.1
/motherboard_top/ftdi/ftdi_1v8: C19.2, C24.2, C26.2, C28.2, U11.12 (VCORE), U11.37 (VCORE), U11.49 (VREGOUT), U11.64 (VCORE)
/motherboard_top/ftdi/ftdi_eeclk: U11.62 (EECLK), U12.11 (SRCLK)
/motherboard_top/ftdi/ftdi_eecs: U11.63 (EECS), U12.12 (RCLK)
/motherboard_top/ftdi/ftdi_eedata: U11.61 (EEDATA), U12.14 (SER)
/motherboard_top/ftdi/ftdi_pwren: R47.1, U11.60 (~PWREN), U12.13 (~OE)
/motherboard_top/ftdi_jtag_src_enB: U15.4, U19.15 (~OE)
/motherboard_top/ftdi_spi_cs: R71.2, R92.2, U11.29 (BDBUS3), U17.14, U21.2
/motherboard_top/ftdi_spi_miso: U11.28 (BDBUS2), U20.14, U21.14
/motherboard_top/ftdi_spi_mosi: R94.2, U20.11, U21.11
/motherboard_top/ftdi_spi_sck: R72.2, R93.2, U17.11, U21.5
/motherboard_top/memory/nor_cs: R48.2, U13.1 (~CS), U14.1 (B2)
/motherboard_top/memory/sd_cs: J19.2 (DAT3/CD), R49.2, U14.3 (B1)
/motherboard_top/mgmt_clk: J4.5, R32.2, U7.3 (OUT)
/motherboard_top/mgmt_csb: J12.1, U21.4, U31.2
/motherboard_top/mgmt_sck: J12.7, U21.7, U31.5
/motherboard_top/mgmt_sdi: J12.3, U21.9, U31.14
/motherboard_top/mgmt_sdo: J12.5, U21.12, U31.11
/motherboard_top/rck_mem_cs: J11.1, R98.2, U14.4 (A), U17.12
/motherboard_top/rck_mem_io2: J11.6, U13.3 (~WP/IO_{2}), U20.4
/motherboard_top/rck_mem_io3: J11.8, U13.7 (~HOLD/~RESET/IO_{3}), U20.7
/motherboard_top/rck_mem_miso_i01: J11.5, R66.1, R67.2, U13.2 (DO/IO_{1}), U20.12
/motherboard_top/rck_mem_mosi_io0: J11.3, J19.3 (CMD), U13.5 (DI/IO_{0}), U20.9
/motherboard_top/rck_mem_sck: J11.7, J19.5 (CLK), R99.2, U13.6 (CLK), U17.9
/motherboard_top/rck_mem_source_enB: U16.4, U17.15 (~OE), U20.15 (~OE)
/motherboard_top/spi_mgmt_enb: U16.2, U18.4, U21.15 (~OE)
GND: C1.2, C2.2, C3.2, C4.1, C5.2, C6.2, C7.2, C8.1, C9.2, C10.1, C11.2, C12.1, C13.2, C14.2, C15.1, C16.1, C17.1, C18.1, C19.1, C20.1, C21.2, C22.1, C23.1, C24.1, C25.1, C26.1, C27.1, C28.1, C29.1, C30.1, C31.1, C32.1, C33.1, C34.1, C35.2, C36.2, C37.2, C38.2, C39.2, C40.2, C41.2, C48.1, C49.1, C50.2, C51.2, C52.2, C53.2, D1.1 (K), D2.1 (K), D3.1 (K), D4.1 (K), D5.1 (K), D6.1 (K), D7.1 (K), D8.1 (K), D9.1 (A1), D10.1 (A1), D11.1 (A1), J1.2 (Ext), J2.2 (Ext), J3.4, J3.6, J3.8, J3.11, J3.13, J3.15, J3.17, J3.19, J3.21, J3.23, J3.25, J3.27, J3.29, J3.31, J3.32, J3.36, J3.37, J3.38, J3.40, J4.2, J4.4, J4.6, J4.8, J4.10, J4.12, J4.14, J4.16, J4.18, J4.20, J4.21, J4.22, J4.24, J4.26, J4.28, J4.30, J4.39, J9.2 (Ext), J10.9, J10.10, J11.9, J11.10, J12.9, J12.10, J13.2, J13.9, J13.10, J14.9, J14.10, J15.9, J15.10, J16.9, J16.10, J17.9, J17.10, J18.5 (GND), J19.6 (VSS), JP1.1 (A), JP2.1 (A), R1.1, R2.2, R3.2, R5.2, R12.2, R13.2, R19.2, R22.2, R28.1, R29.1, R31.1, R32.1, R33.1, R34.1, R36.2, R37.2, R57.1, R58.1, R91.2, SW1.2 (B), U1.8 (GND), U1.19 (GND), U1.20 (GND), U1.22 (GND), U1.49 (GND), U1.60 (GND), U1.71 (GND), U1.72 (GND), U1.81 (GND), U1.92 (GND), U1.104 (AGND), U1.111 (GND), U1.126 (GND), U1.135 (GND), U1.143 (GND), U1.144 (GND), U2.4 (Vss), U3.2 (GND), U3.5 (DIR), U4.3 (GND), U5.2 (GND), U5.5 (DIR), U6.1 (1i), U6.2 (2i), U6.3 (3i), U6.4 (4i), U6.5 (4o), U7.2 (GND), U8.2 (GND), U8.5 (DIR), U9.2 (GND), U10.2 (GND), U11.1 (GND), U11.5 (GND), U11.10 (AGND), U11.11 (GND), U11.13 (TEST), U11.15 (GND), U11.25 (GND), U11.35 (GND), U11.47 (GND), U11.51 (GND), U12.8 (GND), U13.4 (GND), U14.2 (GND), U15.3 (GND), U16.3 (GND), U17.8 (GND), U18.3 (GND), U19.8 (GND), U20.8 (GND), U21.8 (GND), U29.8 (GND), U30.8 (GND), U31.8 (GND), U32.8 (GND), U33.1 (1i), U33.2 (2i), U33.3 (3i), U33.4 (4i), U34.1 (1i), U34.2 (2i), U34.3 (3i), U34.4 (4i), Y1.2, Y1.4, Y2.8 (GND), Y3.2, Y3.4
unnamed: C51.1, R84.2
unnamed: C52.1, R86.2
unnamed: D1.2 (A), R39.1
unnamed: D2.2 (A), R40.1
unnamed: D3.2 (A), R41.1
unnamed: D4.2 (A), R42.1
unnamed: D5.2 (A), R43.2
unnamed: D6.2 (A), R44.2
unnamed: D7.2 (A), R45.2
unnamed: D8.2 (A), R46.2
unnamed: J3.30, R89.2
unnamed: J4.9, R100.1
unnamed: J4.11, R101.1
unnamed: J4.13, R102.1
unnamed: J4.15, R103.1
unnamed: J4.25, R88.1
unnamed: J18.6 (Shield), JP1.2 (B)
unnamed: J19.7 (DAT0), R66.2
unnamed: J19.11 (SHIELD), JP2.2 (B)
unnamed: R35.2, R36.1, R38.1
unnamed: R57.2, U20.5
unnamed: R58.2, U20.2
unnamed: R87.1, U31.3
unnamed: R80.2, U3.3 (A)
unnamed: U4.4, U5.4 (B)
unnamed: R34.2, R70.2, U10.3 (B1)
unnamed: U8.3 (A), U10.1 (B2)
unnamed: R96.1, U11.16 (ADBUS0)
unnamed: R95.1, U11.17 (ADBUS1)
unnamed: R97.1, U11.19 (ADBUS3)
unnamed: R93.1, U11.26 (BDBUS0)
unnamed: R94.1, U11.27 (BDBUS1)
unnamed: R64.1, U11.7 (DM)
unnamed: R65.2, U11.8 (DP)
unnamed: C15.2, U11.2 (OSCI), Y3.3
unnamed: C16.2, U11.3 (OSCO), Y3.1
unnamed: R37.1, U11.6 (REF)
unnamed: R43.1, U12.15 (QA)
unnamed: R39.2, U12.1 (QB)
unnamed: R44.1, U12.2 (QC)
unnamed: R40.2, U12.3 (QD)
unnamed: R45.1, U12.4 (QE)
unnamed: R41.2, U12.5 (QF)
unnamed: R46.1, U12.6 (QG)
unnamed: R42.2, U12.7 (QH)
unnamed: U29.15 (~OE), U30.15 (~OE), U31.15 (~OE), U32.15 (~OE)
unnamed: R25.1, Y2.10 (CLK0)
unnamed: R26.1, Y2.9 (CLK1)
unnamed: R27.1, Y2.6 (CLK2)
unnamed: C4.2, Y1.3, Y2.2 (XA)
unnamed: C5.1, Y1.1, Y2.3 (XB)
VBUS: D11.2 (A2), J18.1 (VBUS), R35.1

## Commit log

2025-10-02 submodule in open source boards
    [breakout-daughter.kicad_pcb, breakout-daughter.kicad_sch, motherboard.kicad_pcb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]
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2025-10-08 add hierarchy demo for clock sources
    [clock_sources.kicad_sch, motherboard.kicad_sch]
2025-10-08 add schematic for clock generator, some symbols
    [clock_sources.kicad_sch, motherboard.kicad_sch]
2025-10-09 update signal supporting ckts
    [ana_buffers.kicad_sch, chip_support_misc.kicad_sch, clock_sources.kicad_sch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]
2025-10-10 clean up supporting blocks; add nucleo symbol
    [ana_buffers.kicad_sch, chip_support_misc.kicad_sch, clock_sources.kicad_sch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]
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2025-10-20 move daughterboard to subprj folder
    [DF40C-50DP-0.4V_51_.step, analog_connectors.kicad_sch, breakout-daughter.kicad_pcb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]
2025-10-20 add footprints for signal conditioning
    [ana_buffers.kicad_sch, chip_support_misc.kicad_sch, clock_sources.kicad_sch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]
2025-10-22 update motheboard schems to include conn
    [ana_buffers.kicad_sch, chip_support_misc.kicad_sch, clock_sources.kicad_sch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]
2025-10-22 in-class work at schems
    [debug_headers.kicad_sch, motherboard.kicad_sch]
2025-10-23 clean up some pull up/downs
    [ana_buffers.kicad_sch, clock_sources.kicad_sch, debug_headers.kicad_sch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]
2025-10-24 add jlc stackup, size pulldowns
    [ana_buffers.kicad_sch, chip_support_misc.kicad_sch, clock_sources.kicad_sch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]
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2025-10-26 add mezzanine symbol/footprint, init daughterboard placement
    [DF40C-50DP-0.4V_51_.step, sky130_nfc_daughter.kicad_pcb, sky130_nfc_daughter.kicad_sch]
2025-10-26 daughter placement v1, add 3D models for mezzanine + uFL
    [DF40C-40DP-0.4V_51_.stp, DF40C-40DS-0.4V_51_.stp, U.FL-R-SMT-1_80_.stp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]
2025-10-26 update uFL 3D model
    [sky130_nfc_daughter.kicad_pcb]
2025-10-27 Added most of nucleo domain to the motherboard schematic
    [motherboard.kicad_sch]
2025-10-27 resaved maybe more updates on the motherboard schematic
    [motherboard.kicad_sch]
2025-10-27 Added the irq and irq2 inputs to the nucleo
    [motherboard.kicad_sch]
2025-10-27 Added the rest of the ports
    [motherboard.kicad_sch]
2025-10-27 add 3D models with rel paths, add stitching via footprint, update daughter pcb schematic
    [sky130_nfc_daughter.kicad_pcb, sky130_nfc_daughter.kicad_sch]
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2025-10-31 clean up schematics, add proper connectors
    [ana_buffers.kicad_sch, chip_connection.kicad_sch, chip_support_misc.kicad_sch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]
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2025-11-01 combine hierarchy of all sans power
    [ana_buffers.kicad_sch, chip_connection.kicad_sch, chip_support_misc.kicad_sch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]
2025-11-01 add some daughterboard routing
    [sky130_nfc_daughter.kicad_pcb, sky130_nfc_daughter.kicad_sch]
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2025-11-03 scoreboard! scoreboard! wait... what?
    [motherboard_top.kicad_sch, pmic_on_boarding.kicad_sch, pmic_supplies.kicad_sch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]
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2025-11-03 daughterboard routing, changed some mezzanine pins - more to come
    [sky130_nfc_daughter.kicad_pcb, sky130_nfc_daughter.kicad_sch]
2025-11-03 partial update to use STM board, updated muxing of FTDI
    [debug_headers.kicad_sch, ftdi.kicad_sch, memory.kicad_sch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]
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2025-11-05 pmic switching schem done
    [pmic_on_boarding.kicad_sch, pmic_supplies.kicad_sch, pmic_switching.kicad_sch]
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2025-11-05 complete signal routing on daughterboard, TODO: power/gnd connections
    [sky130_nfc_daughter.kicad_pcb, sky130_nfc_daughter.kicad_sch]
2025-11-05 2V5 LDO symbol in its own dir
    [LT1761ES5-BYPTRMPBF.step, pmic_supplies.kicad_sch]
2025-11-07 add JLC part num for parts, footprints
    [ana_buffers.kicad_sch, chip_connection.kicad_sch, chip_support_misc.kicad_sch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]
2025-11-07 messing around with floorplanning
    [motherboard.kicad_pcb]
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2025-11-10 more daughterboard routing, power focus
    [sky130_nfc_daughter.kicad_pcb]
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2025-11-10 daughterboard routing, 90% done
    [sky130_nfc_daughter.kicad_pcb, sky130_nfc_daughter.kicad_sch]
2025-11-10 add aux SPI dual-master to drive caravel CPU
    [chip_connection.kicad_sch, motherboard.kicad_sch, motherboard_top.kicad_sch]
2025-11-10 2V5 added to part lib (again?), supplies schem done?
    [pmic_supplies.kicad_sch]
2025-11-10 note on bypass cap on schem
    [pmic_supplies.kicad_sch]
2025-11-10 finish daughter routing + silk
    [sky130_nfc_daughter.kicad_pcb, sky130_nfc_daughter.kicad_sch]
2025-11-10 fuses, ferrite bead, 5V0 selection connector
    [pmic_on_boarding.kicad_sch, pmic_supplies.kicad_sch, pmic_switching.kicad_sch]
2025-11-10 supply connectors, solder bridges
    [pmic_on_boarding.kicad_sch, pmic_supplies.kicad_sch, pmic_switching.kicad_sch]
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2025-11-10 fuse, fb info in values
    [pmic_on_boarding.kicad_sch, pmic_switching.kicad_sch]
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2025-11-11 add qfn small epad footprint, update silk on daughterboard, add fiducials, adjust mezzanine spacing
    [sky130_nfc_daughter.kicad_pcb, sky130_nfc_daughter.kicad_sch]
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2025-11-12 need to map mthrbrd to nucleo + doc online
    [motherboard_top.kicad_sch]
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2025-11-17 halfway done routing to edge, next is analog header, gnd
    [motherboard.kicad_pcb]
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2025-12-10 no erc errors but on root
    [motherboard.kicad_sch, motherboard_top.kicad_sch, pmic_switching.kicad_sch]

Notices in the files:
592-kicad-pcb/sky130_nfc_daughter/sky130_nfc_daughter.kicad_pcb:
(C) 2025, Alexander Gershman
